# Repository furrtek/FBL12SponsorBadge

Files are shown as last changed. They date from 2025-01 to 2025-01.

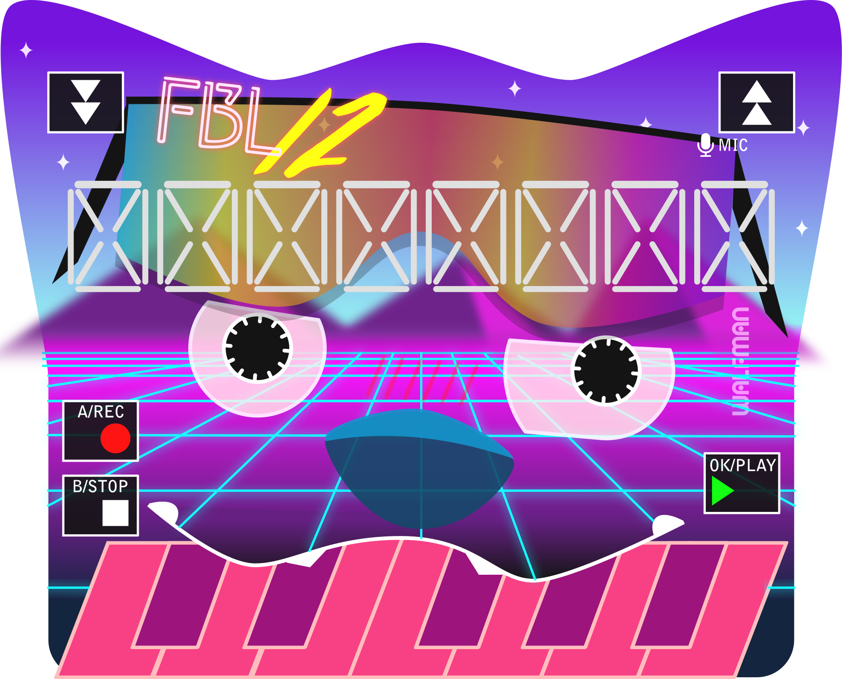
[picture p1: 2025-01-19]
art/art_b_top2.png

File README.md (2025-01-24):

# FBL12SponsorBadge

Super sponsor convention badge for the 12th edition of FBL

* Custom segment display
* Microphone and speaker
* Non-volatile audio storage
* Touch-based digital synth
* Bidirectional IR communication
* Embedded LiPo battery with USB-C charger

# Tech stuff

Any weird design choices were made for cost optimization (i.e. part was the cheapest at the time)

* Can be assembled by hand, smallest part is 0603
* Full BOM except screws can be purchased from LCSC
* PCBs all 2-layers except backboard (no copper at all)
* Fw written in plain C with ST libraries (HAL only used for USB and touch sensing, everything else is LL)
* Custom USB bootloader to update MCU and ext flash with UF2 files

# IR frame format

TODO

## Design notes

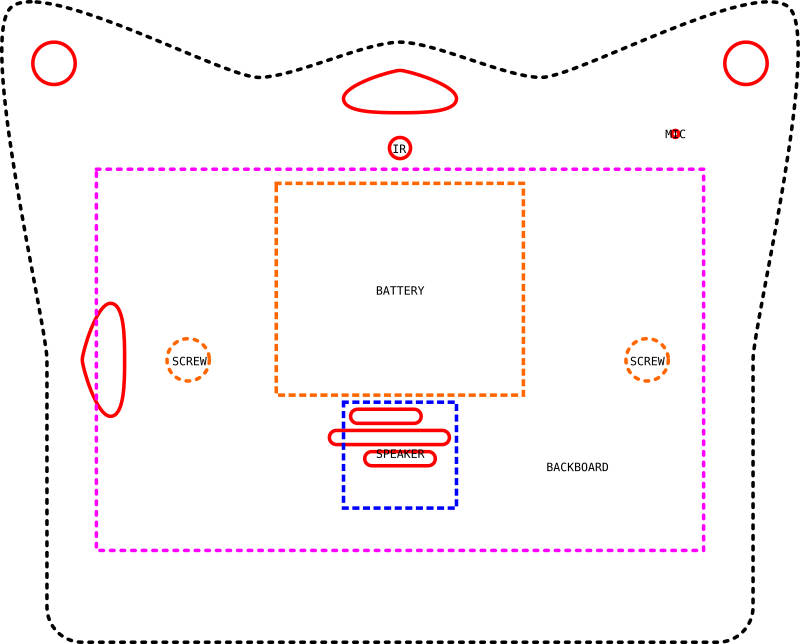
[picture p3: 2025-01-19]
art/outline.png

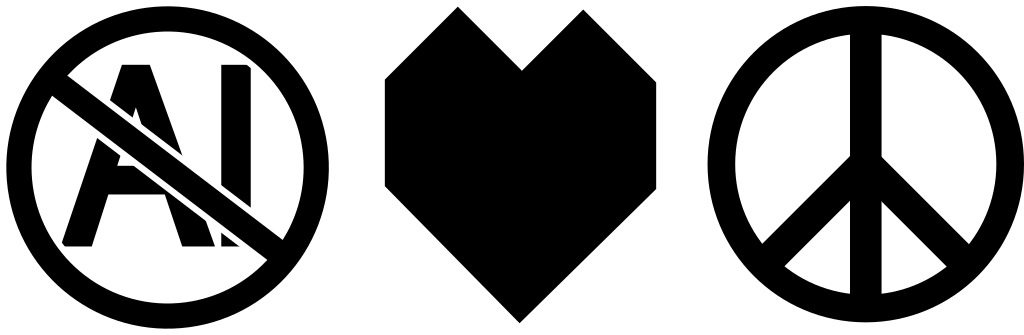
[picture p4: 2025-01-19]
art/backboard_bot.png

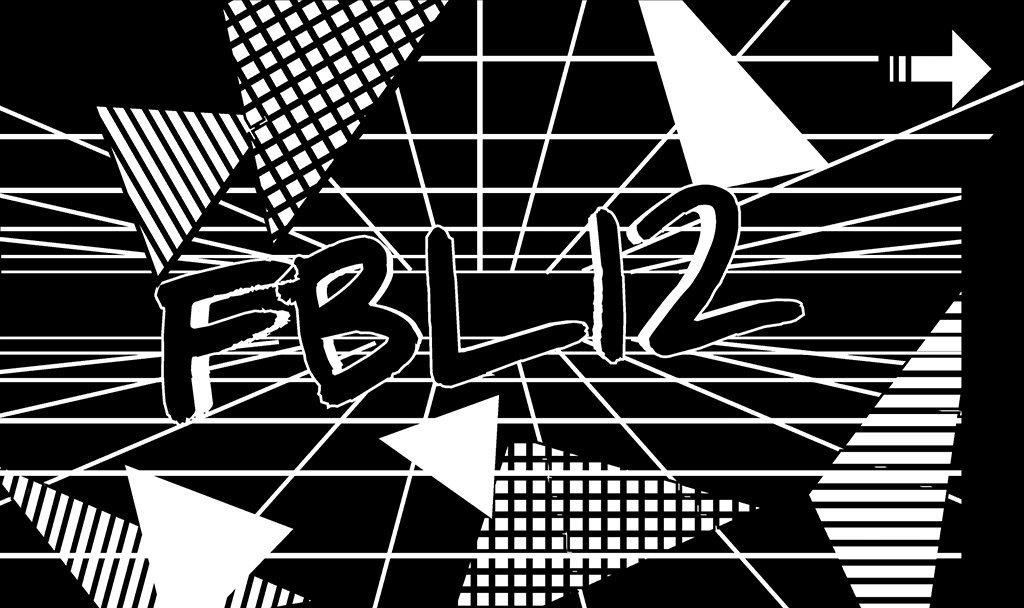
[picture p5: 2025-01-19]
art/backboard_top.png

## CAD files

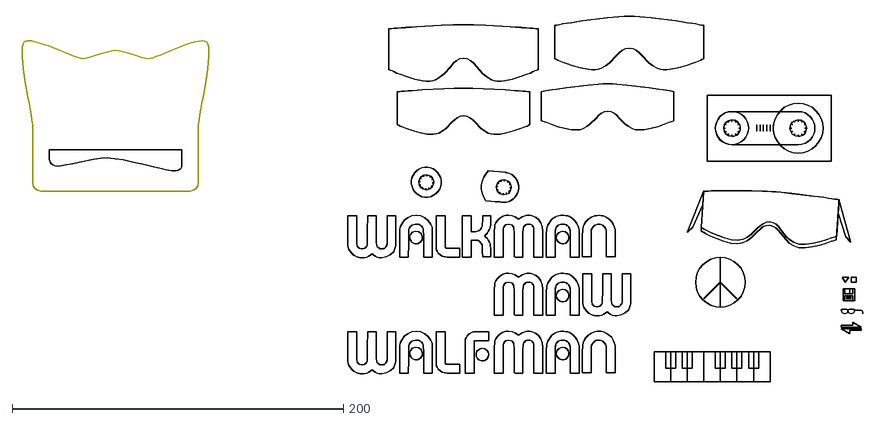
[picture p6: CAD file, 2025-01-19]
art/badge_fbl1.dxf
511.0 x 220.5

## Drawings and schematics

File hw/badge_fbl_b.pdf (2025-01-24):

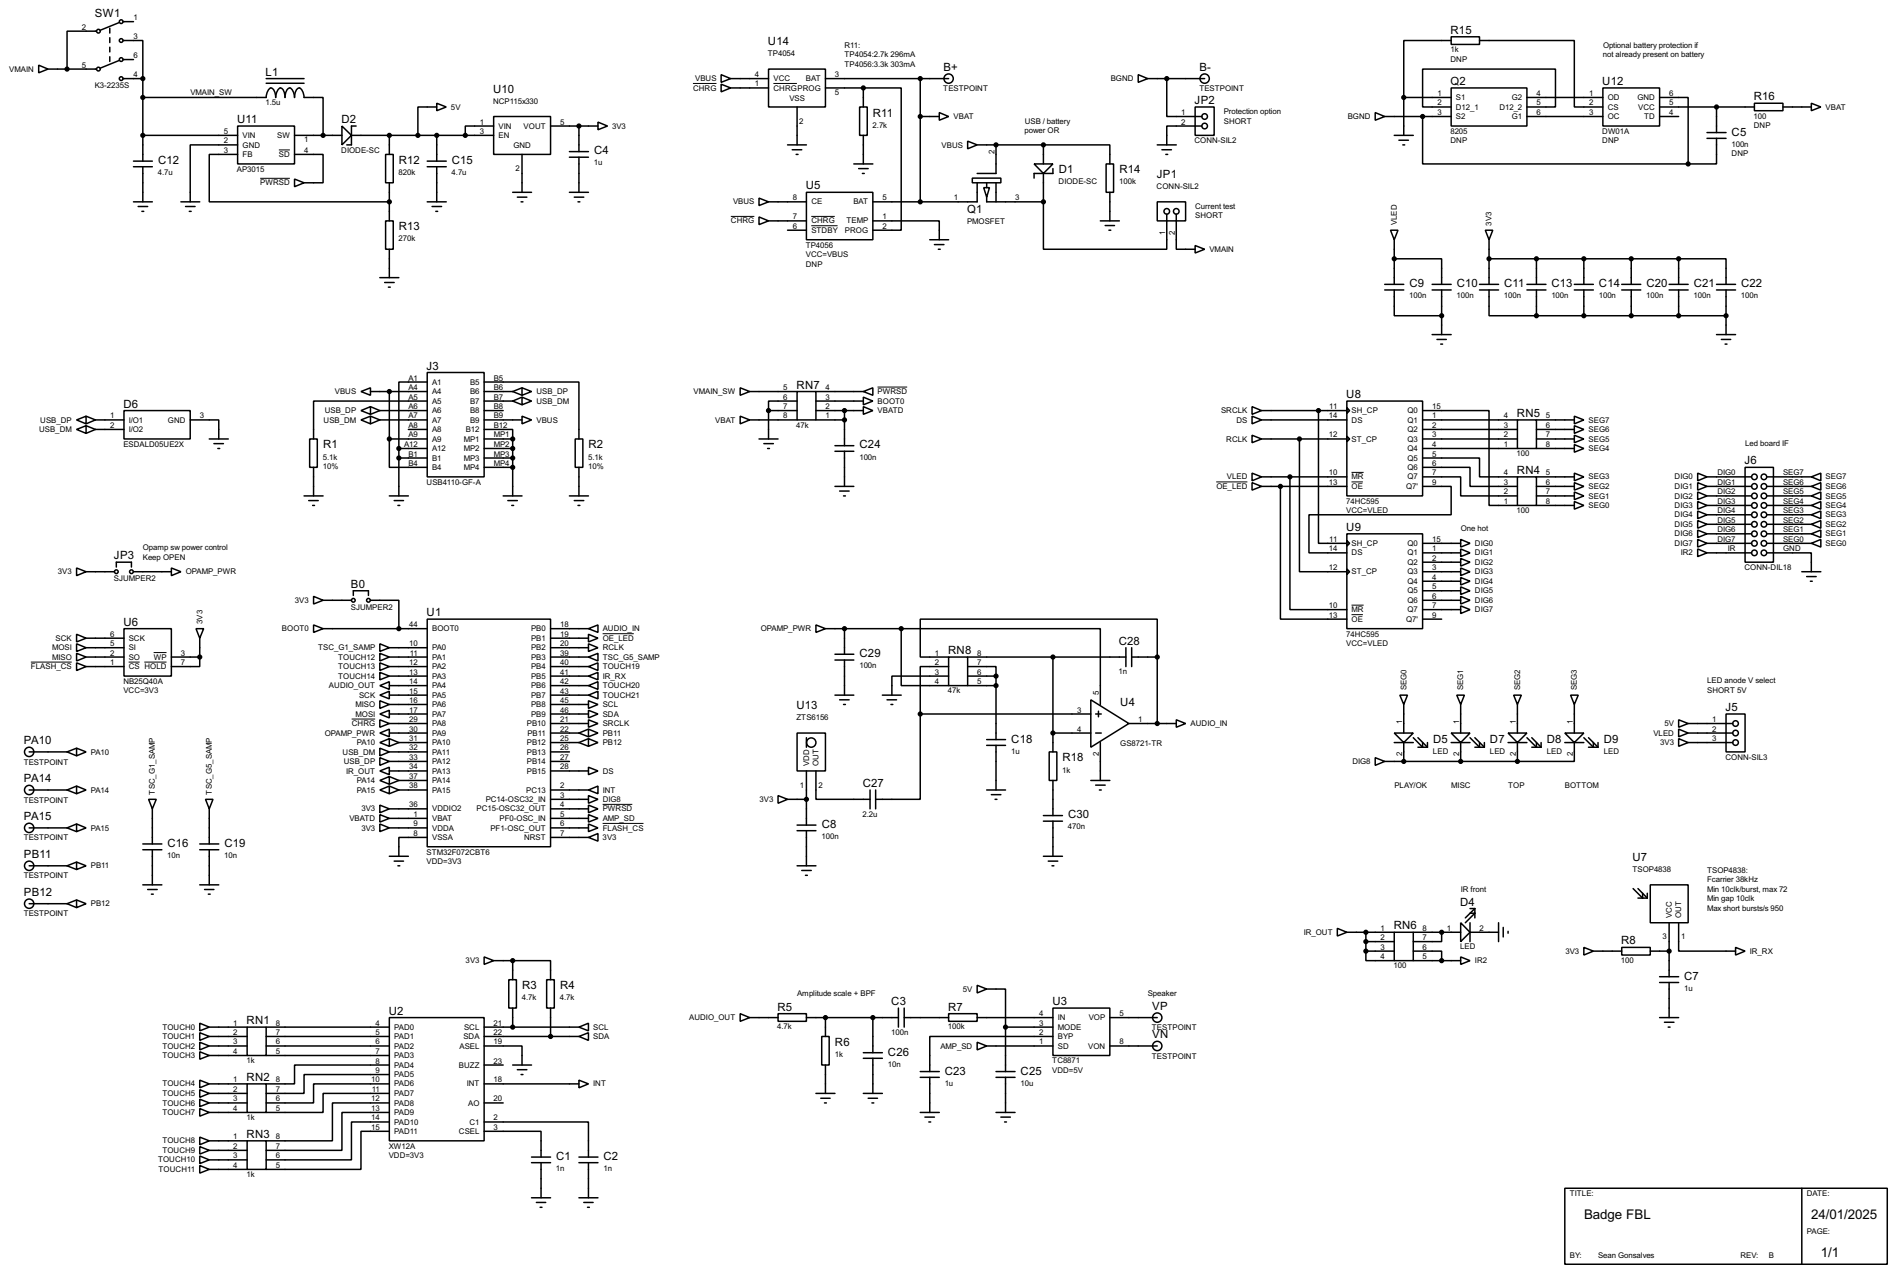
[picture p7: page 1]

Optional battery protection if not already present on battery

USB / battery power OR

USB_DP USB_DM

1 Q2 | 3
2 Q3 3 Q4 | 2

4 Q5 | 1
5 Q6

Opamp sw power control Keep OPEN

LED anode V select SHORT 5V

TSOP4838
TSOP4838: Fcarrier 38kHz Min 10clk/burst, max 72 Min gap 10clk Max short bursts/s 950 R8

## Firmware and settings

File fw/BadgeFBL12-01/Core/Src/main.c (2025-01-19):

// FBL 12 sponsor badge V1
// For STM32F072CBT6
// furrtek 2024

#include <stdio.h>
#include <string.h>
#include "main.h"
#include "init.h"
#include "luts.h"
#include "touch.h"
#include "audio.h"
#include "flash.h"
#include "display.h"
#include "ir.h"
#include "user_data.h"
#include "idle.h"
#include "testmode.h"
#include "synth.h"
#include "misc.h"
#include "rec.h"

// UI:																					STATE_IDLE
// REC button long
//	Blink REC LED, select BOOP/LEFT/RIGHT/ALERT/VOICE with up/down, cancel with STOP	STATE_REC_SEL
//	PLAY button long -> choose which predef sample to use								STATE_REC_PREDEF
//		Select with up/down, autoplay on select, chose with REC, cancel with STOP
//	Keep REC pressed: record mic with progressbar										STATE_REC_ACTIVE
//		REC release: goto PITCH
//	Pitch
//		Play back recording or predef, show "PITCH"										STATE_REC_PITCH
//		Select pitch with up/down, chose with PLAY
//		Cancel with STOP
//		Record to user data
// PLAY button -> synth mode															STATE_SYNTH
// LEAR, REAR, BOOP: Play recorded / predef

// Audio recording:
// TIM2 triggers update interrupts at 8kHz (TIM2_IRQHandler)
// ADC automatically starts a conversion via TIM2's TRGO
// ADC triggers a conversion done interrupt (ADC1_COMP_IRQHandler)
// If audio_op is AUDIO_OP_REC, save sample at audio_buffer_put
// Increment audio_buffer_put, set flag_full if now 0 or 256

// Audio playback:
// TIM2 triggers update interrupts at 8kHz (TIM2_IRQHandler)
// A sample is read from audio_buffer_get and send to the DAC
// Increment audio_buffer_get, set flag_empty if now 0 or 256

// MCU flash memory map: 128kB, 2kB pages, 64 pages, 32 sectors
// Pages 16~62: App
// Page 63: User data (user_data_ptr, 0x0801F800)

// Ext flash memory map: 512kB, 256 byte pages, 2048 pages
// Sample format:
//	Page n: uint16_t length (in pages)
//			IMPLEMENTED IN USER DATA INSTEAD: uint16_t pitch_delta (8.8 fixed point)
//	Pages n+1...: uint8_t pcm_data[]
// Pages 0~1023: Recorded samples (8x 4.96s)
// 	Pages 0~127: Recorded sample BOOP
// 	Pages 128~255: Recorded sample LEFT
// 	Pages 256~383: Recorded sample RIGHT
// 	Pages 384~511: Recorded sample ALERT
// 	Pages 512~639: Recorded sample VOICE
// 	Pages 640~1023: Unused
// Pages 1024~2047: Pre-defined samples (8x 4.96s)

// General IR frame format, all bytes:
//	Command, number of parameters, parameters, sum of all previous bytes

// IR: In idle, transmit species and user ID every BEACON_PERIOD
// Beacon frame:
//	u8 IR_CMD_BEACON
//	u8 length (6)
//	u16 user_id
//	u16 species_a_code
//	u16 species_b_code
//	u8 sum
// Beacon frame received and species match A or B:
//	Transmit species match frame, play sample, display species
// Species match frame: IR_CMD_MATCH 0x02 species_a species_b sum
// Species frame match received and species match A or B:
//	Play sample, display species, start anti-spam timeout

// IR_CMD_TESTMODE:
// 0F 37 0n SS
// n = Test mode 0~3

// ADC for audio input and battery voltage monitoring
// DAC for audio output
// I2C1 for communication with XW12A (can't use because of wonky format !)
// SPI1 for communication with external flash
// SPI2 for LED scanning
// TIM2 for ADC/DAC timing
// TIM3 for IR_RX capture
// TIM14 for LED PWM
// TIM15 for display scan and global tick
// TIM16+TIM17 for IR transmit

uint8_t uid[12];						// MCU UID
uint8_t batt_timer = 0;					// Battery voltage check frame interval
uint8_t match_timer = 0;
uint8_t temp_timer = 0;					// Temp state timer
uint8_t blink_timer = 0;				// LED blinking timer
uint16_t touched_keys = 0;
uint8_t blink_mask = 0;
uint32_t xs_state = 0x1337;

TSC_HandleTypeDef h_tsc;

volatile uint8_t flag_tick;
volatile uint8_t disp_buf[9];

state_t prev_state = STATE_IDLE;
state_t state = STATE_IDLE;

const char str_charge[] = "CHARGE";

void common_enter() {
	memset(touched_rise, 0, sizeof(touched_rise));
	ClearDisp();
	set_brightness(255);
	audio_op = AUDIO_OP_NOP;
}

void enter_temp(const uint8_t time) {
	temp_timer = time;
	state = STATE_TEMP;
}

void enter_alert() {
	ClearDisp();
	PrintTxt(0, "O_O");
	temp_timer = 20;	// 1s
	state = STATE_ALERT;
}

void uart_print(char * buffer) {
	char c;

	while ((c = *buffer++)) {
	    while (!LL_USART_IsActiveFlag_TXE(USART2)) {};
	    LL_USART_TransmitData8(USART2, c);
	}
}

int main(void) {
	uint32_t c = 0;
	uint32_t tick_counter = 0;
	uint8_t batt_percent = 0;

	main_init();

	set_brightness(255);
	ClearDisp();
	disp_buf[8] = 0;

	if (is_charging()) {
		PrintTxt(0, str_charge);
	} else {
		batt_percent = read_batt();
		batt_percent = read_batt();

		if (batt_percent > 80)
			PrintTxt(0, "3/3");
		else if (batt_percent > 50)
			PrintTxt(0, "2/3");
		else if (batt_percent > 20)
			PrintTxt(0, "1/3");
		else
			PrintTxt(0, "0/3");
	}
	PrintNum(1);	// Version
	enter_temp(20);		// 1s
	beep(melody_start);

	char str_buffer[64];
	sprintf(str_buffer, "FBL BADGE APP V1 (%08lx)\n", (*(uint32_t*)ADDR_APPSUM));
	uart_print(str_buffer);

	while (1) {
		// Stuff that must be done ASAP
		if (irrx_flag) {
			// Complete IR frame received
			irrx_flag = 0;
			handle_ir_cmd(irrx_frame.cmd);
		}

		if (state == STATE_TESTMODE) {
			// Nothing ?
		} else if (audio_op == AUDIO_OP_REC) {
			if (flag_full) {
				flag_full = 0;
				if (audio_write_count < audio_write_max) {
					// Write audio_buffer[0...255] or audio_buffer[256...511] to flash
					uint16_t src = (audio_buffer_put >= 256) ? 0 : 256;
					flash_program(audio_write_addr, (uint8_t*)&audio_buffer[src]);

					audio_write_addr += 256;
					audio_write_count++;
				} else {
					rec_stop();
				}
			}
		} else if ((audio_op == AUDIO_OP_PLAY) ||
			((audio_op == AUDIO_OP_SYNTH) && (synth_type == 3))) {
			if (flag_empty) {
				flag_empty = 0;

				// Read to audio_buffer[0...255] or audio_buffer[256...511] from flash
				preload_audio((audio_buffer_get >= 256) ? 0 : 256);
			}
		}

		if (flag_tick) {
			// 600Hz
			flag_tick = 0;

			if (tick_counter >= TICK_PERIOD) {
				// 20Hz
				tick_counter = 0;

				// Keyboard touch
				touched_keys = ReadExtTouch();

				// MCU touch - TODO: Only run this when a complete MCU touch measurement cycle ends
				for (c = 0; c < 12; c++) {
					touched[c] = (touch_val[c] < touch_thr[c]) ? 1 : 0;
					touched_rise[c] = touched[c] & ~touched_prev[c];
				}
				memcpy(touched_prev, touched, sizeof(touched));

				// Battery LED state
				if (is_charging()) {
					led_on(LED_MASK_BATT);	// Keep D7 on
				} else {
					if (batt_percent < 10)
						led_blink(LED_MASK_BATT);	// Blink D7
					else
						led_off(LED_MASK_BATT);		// Keep D7 off
				}

				// LED blinking
				if (!blink_timer) {
					blink_timer = BLINK_PERIOD;
					disp_buf[8] ^= blink_mask;
				} else
					blink_timer--;

				if (state != STATE_REC_ACTIVE) {
					// We can use the ADC whenever we're not using the mic
					if (!batt_timer) {
						// Measure battery voltage
						batt_timer = BATT_PERIOD;
						batt_percent = read_batt();
					} else
						batt_timer--;
				}

				if (state == STATE_TESTMODE) {
					handle_testmode();
				} else if (state == STATE_TEMP) {
					// Do nothing for some time, then go to idle state
					// Used to display stuff temporarily
					if (!temp_timer) {
						enter_idle();
					} else
						temp_timer--;
				} else if (state == STATE_ALERT) {
					// Do nothing for some time, then go to temp state
					if (!temp_timer) {
						ClearDisp();
						//PrintTxt(0, user_data_ptr->species_a);
						PrintTxt(0, "WOLF");	// TODO
						enter_temp(20 * 2);	// 2s
					} else
						temp_timer--;
				} else if (state == STATE_IDLE) {
					handle_idle();
				} else if (state == STATE_SYNTH) {
					handle_synth();
				} else if (state == STATE_REC_SEL) {
					handle_rec_sel();
				} else if (state == STATE_REC_PREDEF) {
					handle_rec_predef();
				} else if (state == STATE_REC_ACTIVE) {
					handle_rec_active();
				} else if (state == STATE_REC_PITCH) {
					handle_rec_pitch();
				}
			} else
				tick_counter++;
		}
	}
}

void Error_Handler(void) {
	__disable_irq();
	while (1) {
	}
}

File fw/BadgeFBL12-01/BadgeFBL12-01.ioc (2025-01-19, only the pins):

Mcu.UserName=STM32F072CBTx
PA0.GPIO_Label=TSC_G1_SAMP
PA0.Signal=TSC_G1_IO1
PA1.GPIO_Label=TOUCH12
PA1.Signal=TSC_G1_IO2
PA10.GPIO_Label=TOUCH18
PA10.Signal=TSC_G4_IO2
PA11.Signal=USB_DM
PA12.Signal=USB_DP
PA13.GPIO_Label=IR_OUT
PA13.Signal=IR_OUT
PA14.GPIO_Label=IR_RX
PA14.Signal=GPIO_Input
PA15.GPIO_Label=nFLASH_CS
PA15.Signal=SPI1_NSS
PA2.GPIO_Label=TOUCH13
PA2.Signal=TSC_G1_IO3
PA3.GPIO_Label=TOUCH14
PA3.Signal=TSC_G1_IO4
PA4.GPIO_Label=AUDIO_OUT
PA4.Signal=COMP_DAC1_group
PA5.GPIO_Label=SCK
PA5.Signal=SPI1_SCK
PA6.GPIO_Label=MISO
PA6.Signal=SPI1_MISO
PA7.GPIO_Label=MOSI
PA7.Signal=SPI1_MOSI
PA8.GPIO_Label=nCHRG
PA8.Signal=GPIO_Input
PA9.GPIO_Label=TSC_G3_SAMP
PA9.Signal=TSC_G4_IO1
PB0.GPIO_Label=AUDIO_IN
PB0.Signal=ADC_IN8
PB1.GPIO_Label=nOE_LED
PB1.Signal=S_TIM14_CH1
PB10.GPIO_Label=SRCLK
PB10.Signal=SPI2_SCK
PB11.GPIO_Label=TSC_G2_SAMP
PB11.Signal=TSC_G6_IO1
PB12.GPIO_Label=TOUCH15
PB12.Signal=TSC_G6_IO2
PB13.GPIO_Label=TOUCH16
PB13.Signal=TSC_G6_IO3
PB14.GPIO_Label=TOUCH17
PB14.Signal=TSC_G6_IO4
PB15.GPIO_Label=DS
PB15.Signal=SPI2_MOSI
PB2.GPIO_Label=RCLK
PB2.Signal=GPIO_Output
PB3.GPIO_Label=TSC_G4_SAMP
PB3.Signal=TSC_G5_IO1
PB4.GPIO_Label=TOUCH19
PB4.Signal=TSC_G5_IO2
PB6.GPIO_Label=TOUCH20
PB6.Signal=TSC_G5_IO3
PB7.GPIO_Label=TOUCH21
PB7.Signal=TSC_G5_IO4
PB8.GPIO_Label=SCL
PB8.Signal=I2C1_SCL
PB9.GPIO_Label=SDA
PB9.Signal=I2C1_SDA
PC13.GPIO_Label=INT
PC13.Signal=GPIO_Input
PC14-OSC32_IN.GPIO_Label=DIG8
PC14-OSC32_IN.Signal=GPIO_Output
PC15-OSC32_OUT.GPIO_Label=nPWRSD
PC15-OSC32_OUT.Signal=GPIO_Output
PF0-OSC_IN.GPIO_Label=AMPSD
PF0-OSC_IN.Signal=GPIO_Output
PF1-OSC_OUT.GPIO_Label=BTN1
PF1-OSC_OUT.Signal=GPIO_Input

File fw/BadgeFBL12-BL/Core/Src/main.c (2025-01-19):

// FBL 12 sponsor badge bootloader
// For STM32F072CBT6
// furrtek 2024

#include <string.h>
#include "main.h"
#include "init.h"
#include "touch.h"
#include "audio.h"
#include "display.h"
#include "usb_device.h"

// MSC bootloader started by touching right ear and nose on power on

// MCU flash memory map: 128kB, 2kB pages, 64 pages, 32 sectors
// Pages 0~15: Bootloader
// Pages 16~62: App
// Page 63: User data (user_data_ptr, 0x0801F800)

// ADC for audio input and battery voltage monitoring
// DAC for audio output
// I2C1 for communication with XW12A (can't use because of wonky format !)
// SPI1 for communication with external flash
// SPI2 for LED scanning
// TIM2 for ADC/DAC timing
// TIM14 for LED PWM
// TIM15 for display scan and global tick

uint32_t uid[3];	// MCU UID
uint8_t app_valid = 0;
uint32_t app_checksum = 0;

TSC_HandleTypeDef htsc;

volatile uint8_t flag_tick;
volatile uint8_t disp_buf[9];

const char str_bootloader[] = "U S B";

char str_buffer[256];

void set_brightness(uint8_t v) {
	LL_TIM_OC_SetCompareCH1(TIM14, ((uint16_t)v * 1000) >> 8);
}

void ShortWait(uint32_t wait) {
	volatile uint32_t wait_loop_index = wait;	// Units of ~10us at 12MHz
	while (wait_loop_index) {
		wait_loop_index--;
	}
}

void run_app() {
	typedef void (*function_ptr_t)(void);
	uint32_t appStack;
	function_ptr_t appEntry;

	appStack = (uint32_t) *((__IO uint32_t *) ADDR_APP);
	appEntry = (function_ptr_t) *(__IO uint32_t*) (ADDR_APP + 4);

	// Copy the app vector table to RAM
	volatile uint32_t *VectorTable = (volatile uint32_t *)0x20000000;
	for (int i = 0; i < 48; i++)
		VectorTable[i] = *(__IO uint32_t*)(ADDR_APP + (i<<2));

	__HAL_RCC_AHB_FORCE_RESET();
	__HAL_RCC_SYSCFG_CLK_ENABLE();
	__HAL_RCC_AHB_RELEASE_RESET();
	__DSB();
	__HAL_SYSCFG_REMAPMEMORY_SRAM();	// Set 0x00000000 to start of RAM where app vector table now is
	__DSB();
	__ISB();

	__set_MSP(appStack);

	appEntry();
}

void uart_print(char * buffer) {
	char c;

	while ((c = *buffer++)) {
	    while (!LL_USART_IsActiveFlag_TXE(USART2)) {};
	    LL_USART_TransmitData8(USART2, c);
	}
}

void start_msc() {
	uart_print("MSC start\n");
	set_brightness(200);
	PrintTxt(0, str_bootloader);
	beep(8000, 2000);
	LL_mDelay(100);
	MX_USB_DEVICE_Init();

	while (1) {	};
}

void check_app() {
	app_valid = 0;

	uint32_t app_size = (*(uint32_t*)ADDR_APPSIZE);
	if ((app_size == 0) || (app_size > SIZE_APP_MAX)) {
		uart_print("App size invalid\n");
		return;
	}

	app_checksum = 0;
	uint32_t * addr = (uint32_t*)ADDR_APP;
	uint32_t * end = (uint32_t*)(ADDR_APP + app_size);
	while (addr < end)
		app_checksum += (*addr++);

	if (app_checksum != (*(uint32_t*)ADDR_APPSUM))
		uart_print("App checksum invalid\n");
	else
		app_valid = 1;
}

int main(void) {
	uint32_t tick_counter = 0;

	ClearDisp();
	disp_buf[8] = 0;

	main_init();

	uart_print("BL V1\n");

	check_app();

	if (!app_valid)
		start_msc();

	while ((touch_val[TOUCH_NOSE] < touch_thr[TOUCH_NOSE]) &&
			(touch_val[TOUCH_REAR] < touch_thr[TOUCH_REAR])) {
		if (flag_tick) {
			// 600Hz
			flag_tick = 0;
			if (tick_counter >= 200) {
				uart_print("Manual entry\n");
				start_msc();
			} else
				tick_counter++;
		}
	}

	uart_print("Starting app\n");
    while (!LL_USART_IsActiveFlag_TC(USART2)) {};

	run_app();
}

void Error_Handler(void) {
	uart_print("Error :(\n");
	__disable_irq();
	while (1) {
	}
}

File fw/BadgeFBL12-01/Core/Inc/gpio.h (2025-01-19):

// FBL 12 sponsor badge V1
// For STM32F072CBT6
// furrtek 2024

#ifndef INC_GPIO_H_
#define INC_GPIO_H_

// Pin definitions
#define INT_Pin LL_GPIO_PIN_13
#define INT_GPIO_Port GPIOC
#define DIG8_Pin LL_GPIO_PIN_14
#define DIG8_GPIO_Port GPIOC
#define nPWRSD_Pin LL_GPIO_PIN_15
#define nPWRSD_GPIO_Port GPIOC
#define AMPSD_Pin LL_GPIO_PIN_0
#define AMPSD_GPIO_Port GPIOF
#define BTN1_Pin LL_GPIO_PIN_1
#define BTN1_GPIO_Port GPIOF
#define TSC_G1_SAMP_Pin LL_GPIO_PIN_0
#define TSC_G1_SAMP_GPIO_Port GPIOA
#define TOUCH12_Pin LL_GPIO_PIN_1
#define TOUCH12_GPIO_Port GPIOA
#define TOUCH13_Pin LL_GPIO_PIN_2
#define TOUCH13_GPIO_Port GPIOA
#define TOUCH14_Pin LL_GPIO_PIN_3
#define TOUCH14_GPIO_Port GPIOA
#define AUDIO_OUT_Pin LL_GPIO_PIN_4
#define AUDIO_OUT_GPIO_Port GPIOA
#define SCK_Pin LL_GPIO_PIN_5
#define SCK_GPIO_Port GPIOA
#define MISO_Pin LL_GPIO_PIN_6
#define MISO_GPIO_Port GPIOA
#define MOSI_Pin LL_GPIO_PIN_7
#define MOSI_GPIO_Port GPIOA
#define AUDIO_IN_Pin LL_GPIO_PIN_0
#define AUDIO_IN_GPIO_Port GPIOB
#define nOE_LED_Pin LL_GPIO_PIN_1
#define nOE_LED_GPIO_Port GPIOB
#define RCLK_Pin LL_GPIO_PIN_2
#define RCLK_GPIO_Port GPIOB
#define SRCLK_Pin LL_GPIO_PIN_10
#define SRCLK_GPIO_Port GPIOB
#define DS_Pin LL_GPIO_PIN_15
#define DS_GPIO_Port GPIOB
#define nCHRG_Pin LL_GPIO_PIN_8
#define nCHRG_GPIO_Port GPIOA
#define IR_OUT_Pin LL_GPIO_PIN_13
#define IR_OUT_GPIO_Port GPIOA
#define TSC_G4_SAMP_Pin LL_GPIO_PIN_3
#define TSC_G4_SAMP_GPIO_Port GPIOB
#define TOUCH19_Pin LL_GPIO_PIN_4
#define TOUCH19_GPIO_Port GPIOB
#define TOUCH20_Pin LL_GPIO_PIN_6
#define TOUCH20_GPIO_Port GPIOB
#define TOUCH21_Pin LL_GPIO_PIN_7
#define TOUCH21_GPIO_Port GPIOB
#define SCL_Pin LL_GPIO_PIN_8
#define SCL_GPIO_Port GPIOB
#define SDA_Pin LL_GPIO_PIN_9
#define SDA_GPIO_Port GPIOB
#define IR_RX_Pin LL_GPIO_PIN_5
#define IR_RX_GPIO_Port GPIOB
#define OPAMP_PWR_Pin LL_GPIO_PIN_9
#define OPAMP_PWR_GPIO_Port GPIOA
#define nFLASH_CS_Pin LL_GPIO_PIN_1
#define nFLASH_CS_GPIO_Port GPIOF
#define DBG_Pin LL_GPIO_PIN_10
#define DBG_GPIO_Port GPIOA

// Debug output pin
#define DBGPIN_RESET LL_GPIO_ResetOutputPin(DBG_GPIO_Port, DBG_Pin);
#define DBGPIN_SET LL_GPIO_SetOutputPin(DBG_GPIO_Port, DBG_Pin);
#define DBGPIN_TOGGLE LL_GPIO_TogglePin(DBG_GPIO_Port, DBG_Pin);

#endif /* INC_GPIO_H_ */

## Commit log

2025-01-19 Let it goooo~
    [badge_fbl1.dxf]
2025-01-24 Added pdf rev B schematic
